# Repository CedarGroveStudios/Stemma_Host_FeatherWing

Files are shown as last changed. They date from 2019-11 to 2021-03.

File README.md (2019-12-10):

# UNTESTED: Stemma Host FeatherWing

### _A Stemma UART/I2C FeatherWing interface for use with a host MCU Feather board._

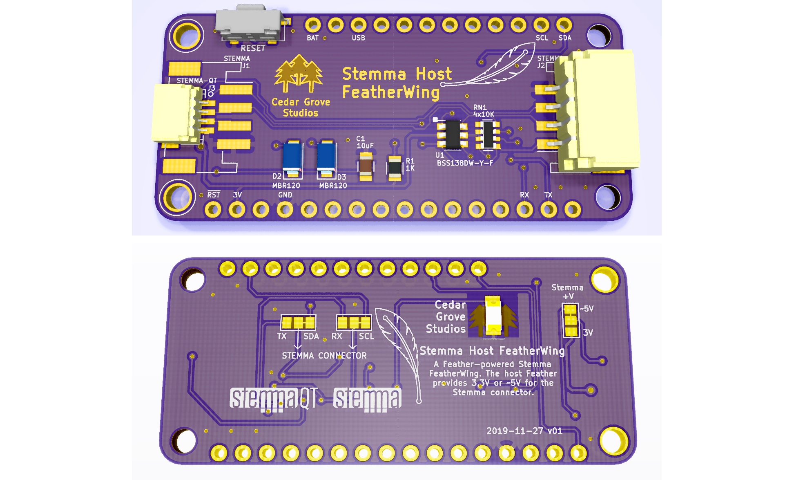
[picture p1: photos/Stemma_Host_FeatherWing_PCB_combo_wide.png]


The Stemma Host FeatherWing is a single Stemma or StemmaQT interface, compatible with the Adafruit Feather format. It is designed for use with a Feather MCU board such as the Feather M4 Express and will selectively communicate via UART (RX/TX) or I2C (SDA/SCL). The Stemma connector power is provided by the host Feather and is selectable for either 3 volts or ~5 volts. Stemma 2.0mm and Stemma-QT 1.0mm connector types are supported. 

For use ONLY with Feather MCU boards that provide at least a 3.3-volt power source. USB or battery power is needed for Stemma ~5-volt signals.

OSH Park project: https://oshpark.com/shared_projects/8VwYkydw

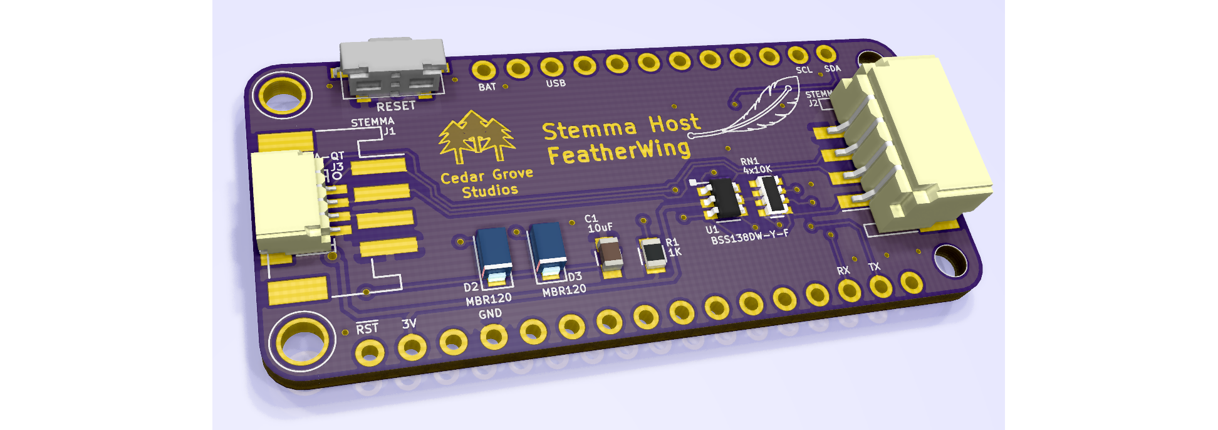
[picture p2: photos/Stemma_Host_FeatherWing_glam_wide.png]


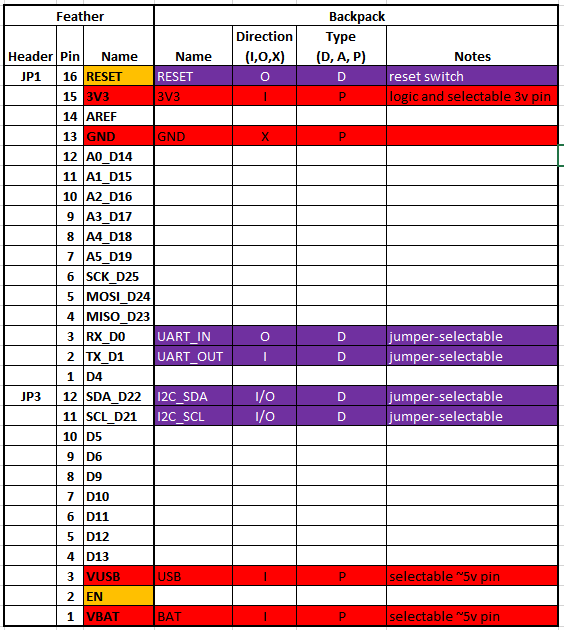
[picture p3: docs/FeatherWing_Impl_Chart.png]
FeatherWing Implementation Chart


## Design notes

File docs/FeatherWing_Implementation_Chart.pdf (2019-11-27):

Feather | Backpack
Header | Pin | Name | Name | Direction (I,O,X) | Type (D, A, P) | Notes
JP1 | 16 | RESET | RESET | O | D | reset switch
| 15 | 3V3 | 3V3 | I | P | logic and selectable 3v pin
| 14 AREF
| 13 | GND | GND | X | P
| 12 A0_D14
| 11 A1_D15
| 10 A2_D16
| 9 A3_D17
| 8 A4_D18
| 7 A5_D19
| 6 SCK_D25
| 5 MOSI_D24
| 4 MISO_D23
| 3 | RX_D0 | UART_IN | O | D | jumper-selectable
| 2 | TX_D1 | UART_OUT | I | D | jumper-selectable
| 1 D4
JP3 | 12 | SDA_D22 | I2C_SDA | I/O | D | jumper-selectable
| 11 | SCL_D21 | I2C_SCL | I/O | D | jumper-selectable
| 10 D5
| 9 D6
| 8 D9
| 7 D10
| 6 D11
| 5 D12
| 4 D13
| 3 | VUSB | USB | I | P | selectable ~5v pin
| 2 EN
| 1 | VBAT | BAT | I | P | selectable ~5v pin

## FeatherWing Implementation Chart

11/26/2019 11:15 PM FeatherWing_Implementation_Chart.xlsx FeatherWing Impl Chart | Page 1 of 1

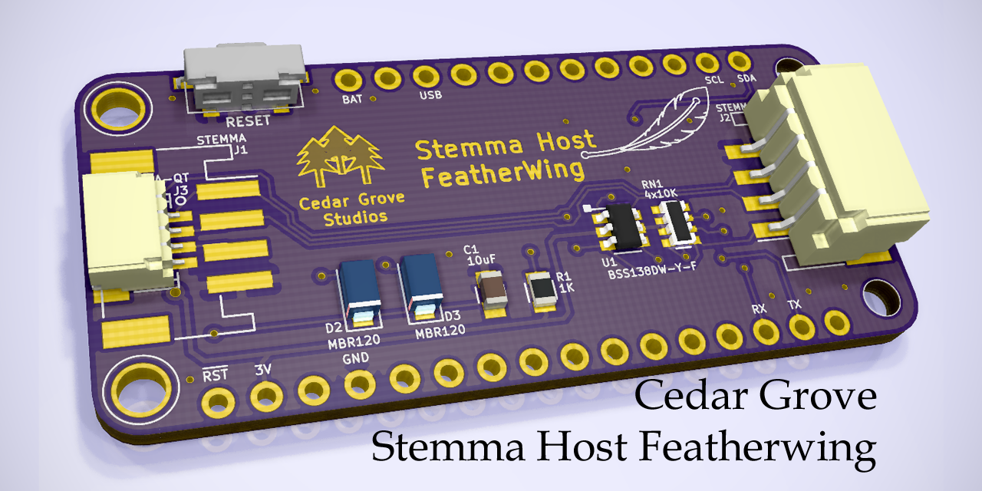
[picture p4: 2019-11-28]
photos/Stemma_Host_FeatherWing_social.png

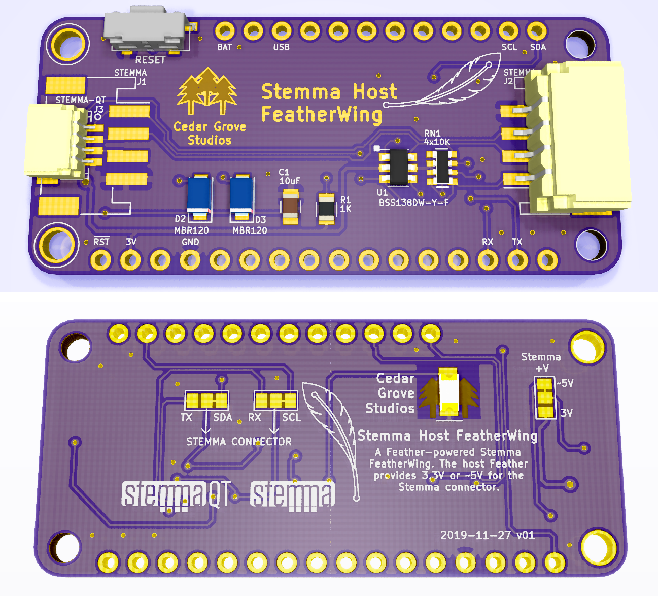
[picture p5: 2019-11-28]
photos/Stemma_Host_FeatherWing_PCB_combo.png

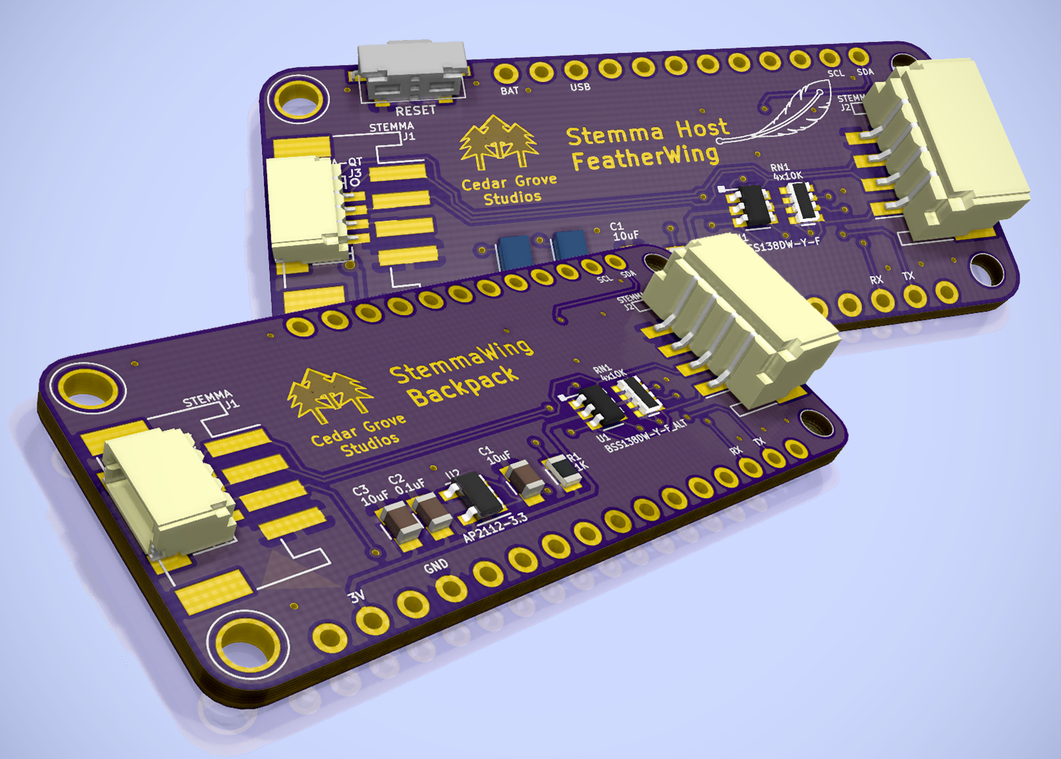
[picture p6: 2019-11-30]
photos/Stemma_Wings_glam.png

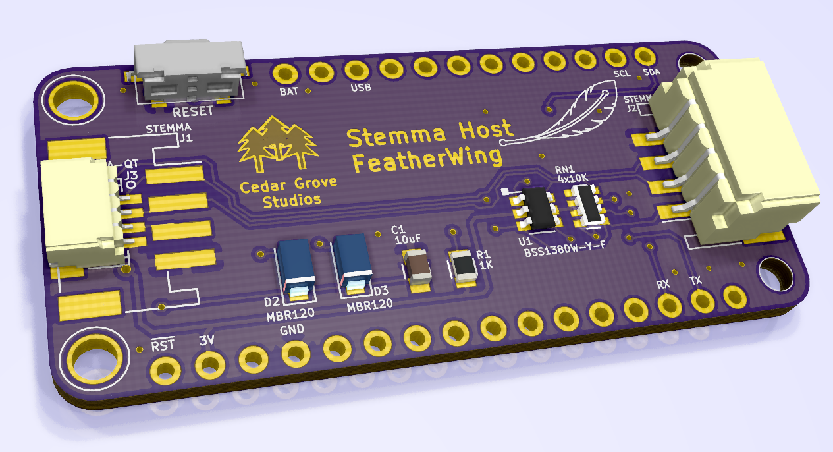
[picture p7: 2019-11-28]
photos/Stemma_Host_FeatherWing_glam.png

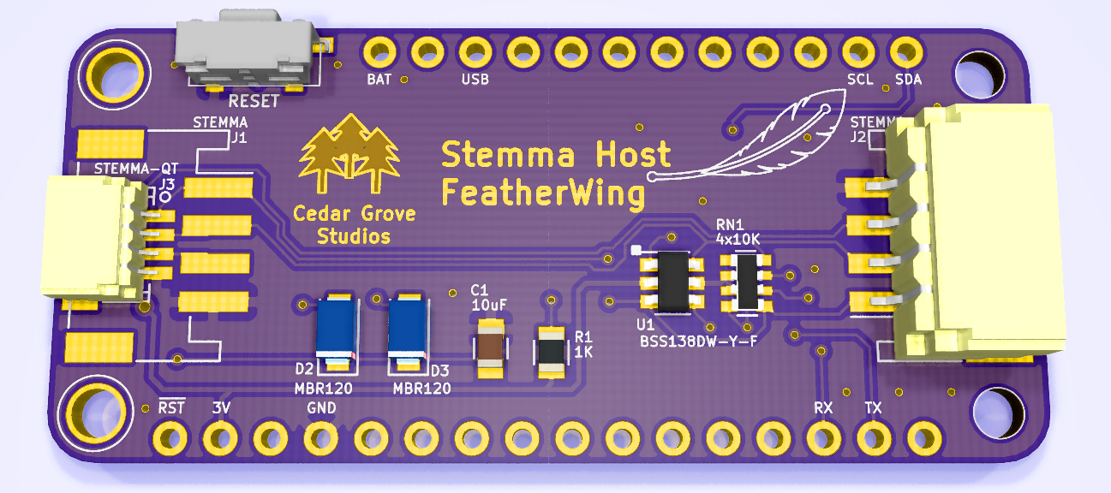
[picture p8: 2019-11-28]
photos/Stemma_Host_FeatherWing.png

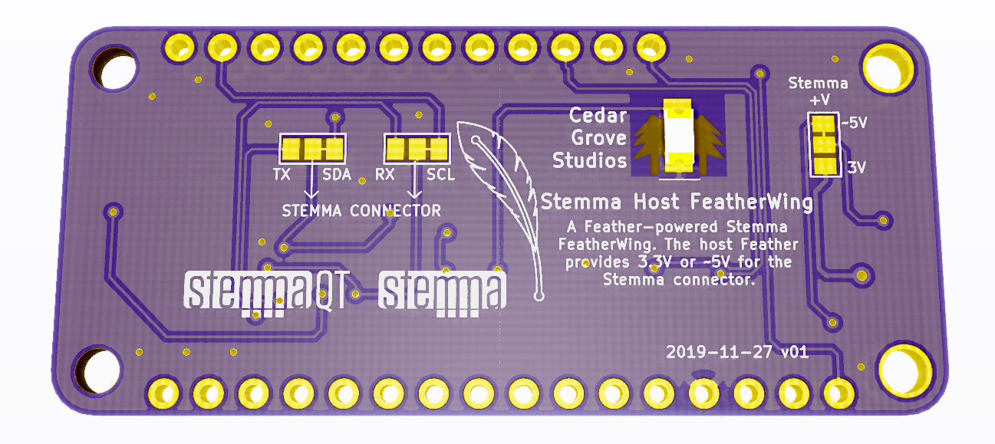
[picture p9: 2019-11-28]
photos/Stemma_Host_FeatherWing_bot.png

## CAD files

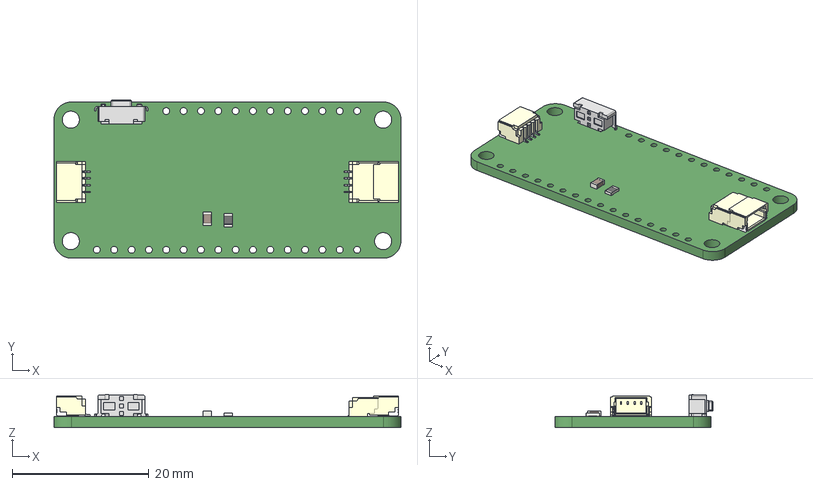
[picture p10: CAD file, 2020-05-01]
PCB/Stemma_Host_FeatherWing.stp
50.8 x 23.2 x 4.85 mm
R_Array_Convex_4x0603
LED_1206
D_SMA_Handsoldering x 2

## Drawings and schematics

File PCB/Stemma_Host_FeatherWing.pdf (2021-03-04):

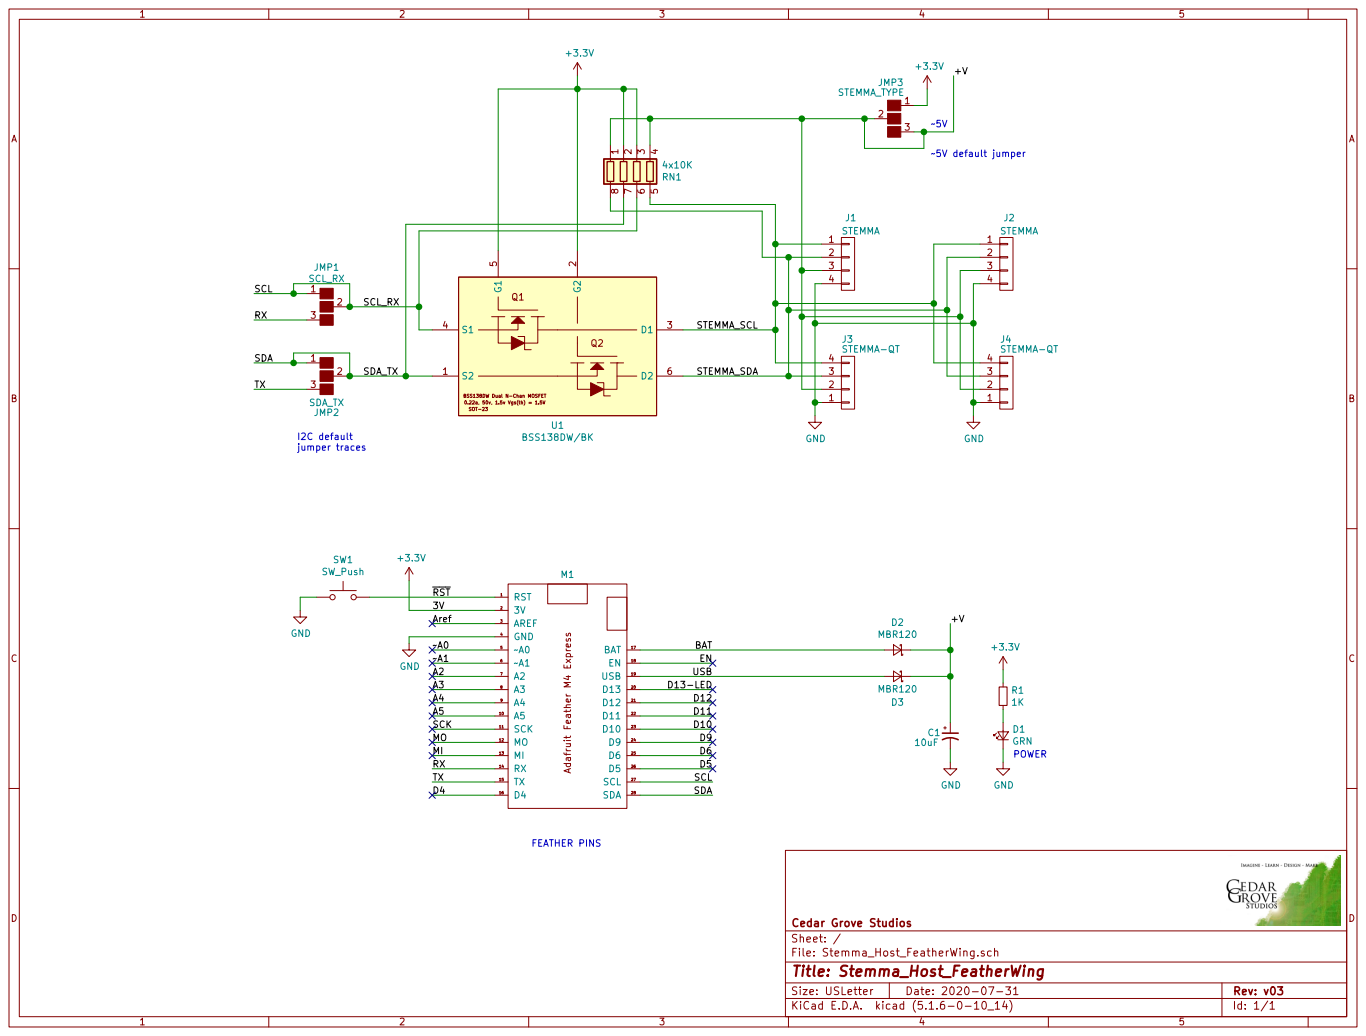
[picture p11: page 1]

File: Stemma_Host_FeatherWing.sch Sheet: / Cedar Grove Studios

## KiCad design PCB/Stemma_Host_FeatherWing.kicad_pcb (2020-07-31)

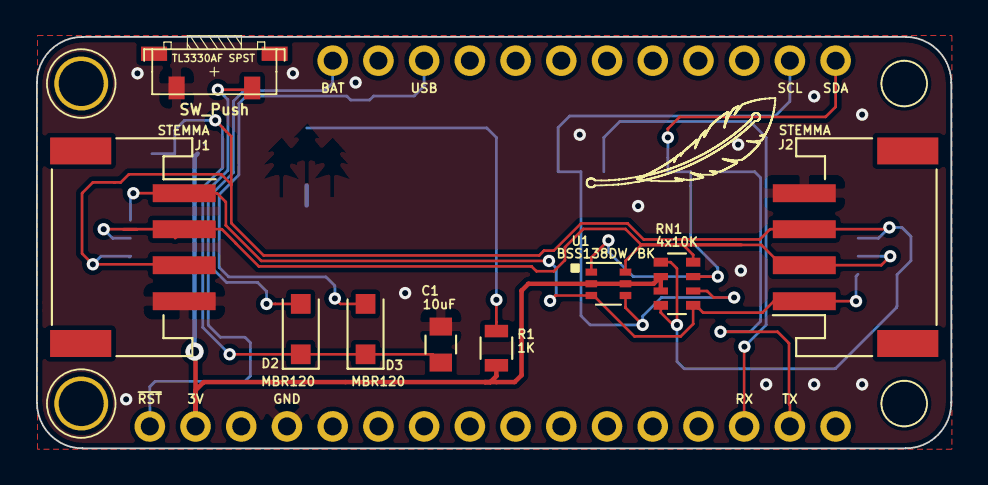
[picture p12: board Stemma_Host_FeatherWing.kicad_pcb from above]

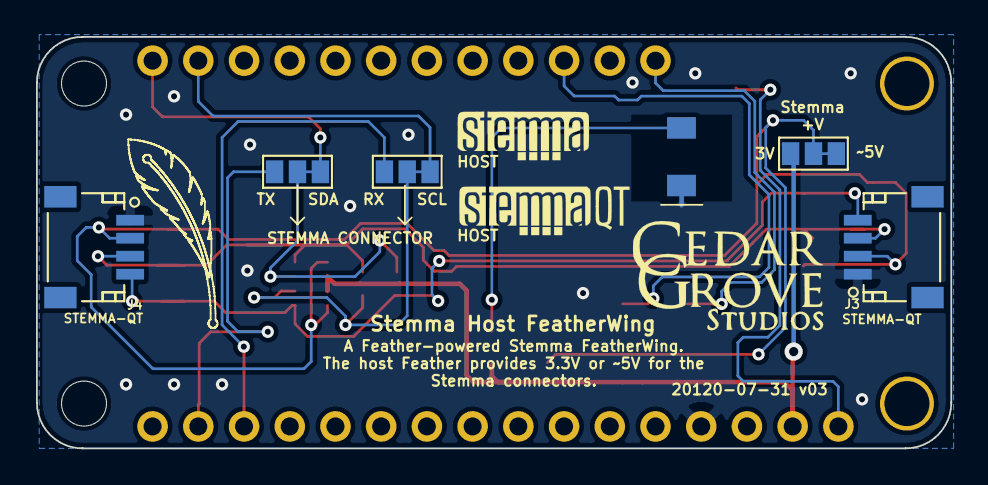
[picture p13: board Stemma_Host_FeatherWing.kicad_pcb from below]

Board: 2 copper layers, 50.8 x 22.9 mm, 16 parts (5 on the bottom side), 13 nets.

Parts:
C1: 10uF; C_0805
D1: GRN; Cedar_Grove_logo_lighted
D2, D3: MBR120; D_SOD-123F
J1, J2: STEMMA; JST_PH_S4B-PH-SM4-TB_04x2.00mm_Angled
J3, J4: STEMMA-QT; JST_SH_SM04B-SRSS-TB_04x1.00mm_Angled
JMP1: SCL_RX; GS3
JMP2: SDA_TX; GS3
JMP3: STEMMA_TYPE; GS3
M1: Feather_M4_Express; Adafruit_Feather_M4_Express_bare
R1: 1K; R_0805
RN1: 4x10K; R_Array_Convex_4x0603
SW1: SW_Push; TL3330AF_SPST_BUTTON_RT-ANGLE_7.8mm_2.5mm_2.5mm
U1: BSS138DW/BK; SOT-363_SC-70-6

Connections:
+3V3: JMP3.1, M1.2, R1.1, RN1.2, RN1.3, U1.2, U1.5
/+V: C1.1, D2.1, D3.1, J1.3, J2.3, J3.2, J4.2, JMP3.2, JMP3.3, RN1.1, RN1.4
/BAT: D2.2, M1.17
/RX: JMP1.3, M1.14
/SCL: JMP1.1, JMP1.2, M1.27, RN1.6, U1.4
/SDA: JMP2.1, JMP2.2, M1.28, RN1.7, U1.1
/STEMMA_SCL: J1.1, J2.1, J3.4, J4.4, RN1.5, U1.3
/STEMMA_SDA: J1.2, J2.2, J3.3, J4.3, RN1.8, U1.6
/TX: JMP2.3, M1.15
/USB: D3.2, M1.19
/~RST: M1.1, SW1.2
GND: C1.2, D1.1, J1.4, J2.4, J3.1, J4.1, M1.4, SW1.1
unnamed: D1.2, R1.2

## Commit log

2019-11-27 initial repo load
    [FeatherWing_Implementation_Chart.xlsx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]
2019-11-27 update with initial design
    [Stemma_Host_FeatherWing-B.Cu.gbl, Stemma_Host_FeatherWing-B.Mask.gbs, Stemma_Host_FeatherWing-B.Paste.gbp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]
2019-11-27 update impl chart
    [FeatherWing_Implementation_Chart.xlsx]
2019-11-27 update design
    [Stemma_Host_FeatherWing.kicad_pcb, Stemma_Host_FeatherWing.sch]
2019-12-10 PCB version update
    [Stemma_Host_FeatherWing-B.Cu.gbl, Stemma_Host_FeatherWing-B.Mask.gbs, Stemma_Host_FeatherWing-B.Paste.gbp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]
2020-07-31 correct stemma-qt pinout
    [Stemma_Host_FeatherWing-B.Cu.gbl, Stemma_Host_FeatherWing-B.Paste.gbp, Stemma_Host_FeatherWing-B.SilkS.gbo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]
2021-03-04 remove duplicate graphics
    [Stemma_Host_FeatherWing.sch]
2021-07-12 update documentation
    [FeatherWing_Implementation_Chart.xlsx]
